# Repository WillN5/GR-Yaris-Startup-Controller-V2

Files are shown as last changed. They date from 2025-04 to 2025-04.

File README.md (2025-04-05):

# GR Yaris Startup Controller V2.0

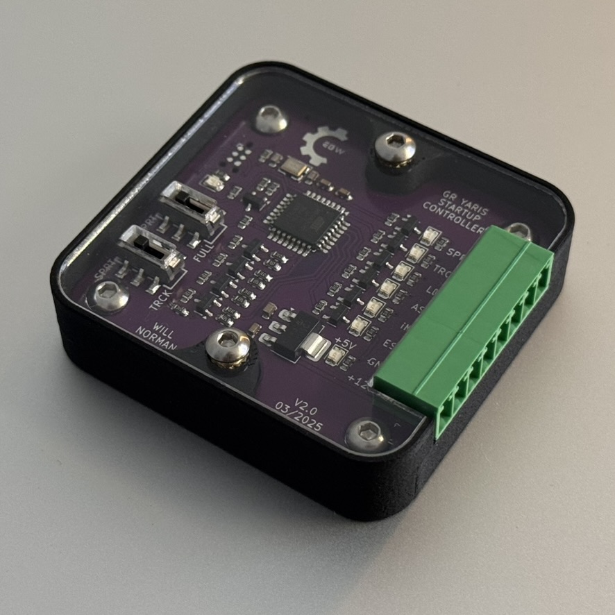
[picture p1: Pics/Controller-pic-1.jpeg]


This device will automatically press any (or all) of the annoying buttons in a GR Yaris when you first start your car:
* Lane Departure Alert (turn off)
* iMT (turn on)
* Auto Stop/Start (turn off)
* Select Sport/Track mode
* Turn ESC to expert mode, or switch ESC fully off

The controller simply presses the buttons (electronically) upon first start up. Original button functionality remains unaffected.

In this repository you will find:
* [Overview & Installation Guide](https://github.com/WillN5/GR-Yaris-Startup-Controller-V2/blob/main/Docs/Overview%20%26%20Install%20Guide.pdf)
* [Car Wiring Information](https://github.com/WillN5/GR-Yaris-Startup-Controller-V2/blob/main/Docs/Car%20Wiring%20Info.pdf)
* [Code](https://github.com/WillN5/GR-Yaris-Startup-Controller-V2/blob/main/Code/Code_Startup_Controller_v2/Code_Startup_Controller_v2.ino)
* [3D Case Files](https://github.com/WillN5/GR-Yaris-Startup-Controller-v2/tree/main/3D%20Files)
* [Pictures](https://github.com/WillN5/GR-Yaris-Startup-Controller-v2/tree/main/Pics)
* [Link to Video Demo](https://youtu.be/CKgJuQoar5g)

Credit for idea goes to MagnusT and his original post here:<br/>
https://www.gr-yaris.co.uk/threads/automatic-shut-off-of-all-lane-assist-everytime-you-start-the-car.2947/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<br/>
This project is a development of that idea to include the additional button presses, wrapped up in a neat package.

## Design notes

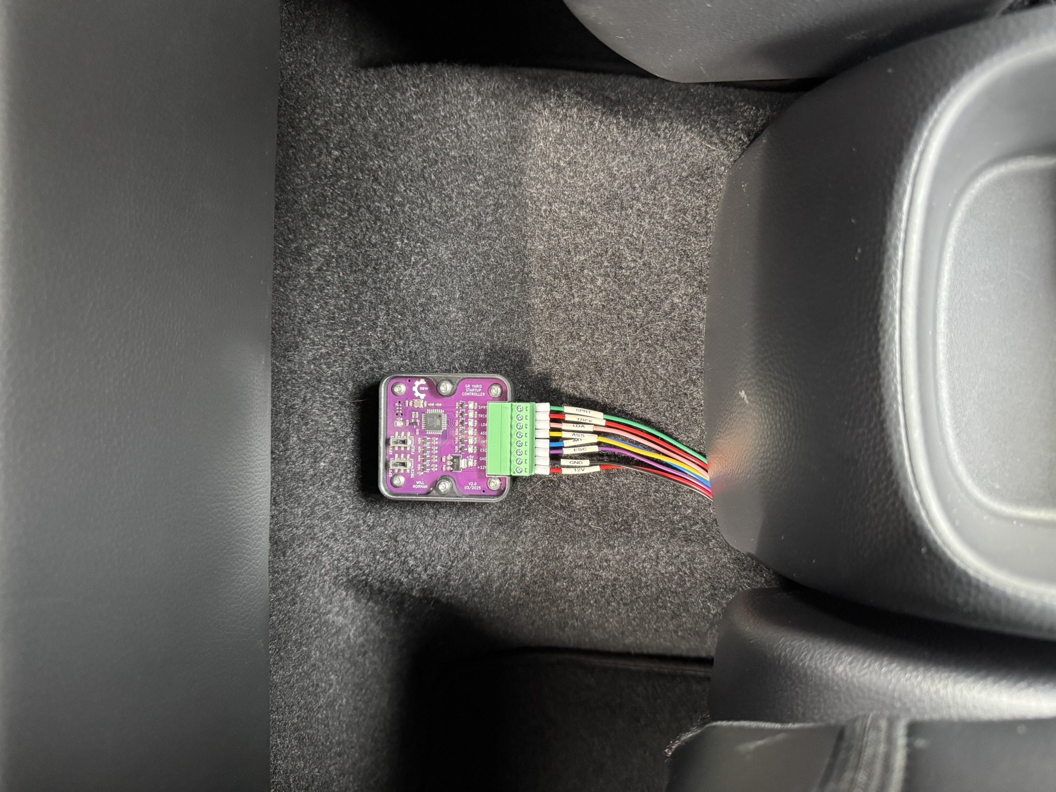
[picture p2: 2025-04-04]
Pics/controller-pic-2.JPEG

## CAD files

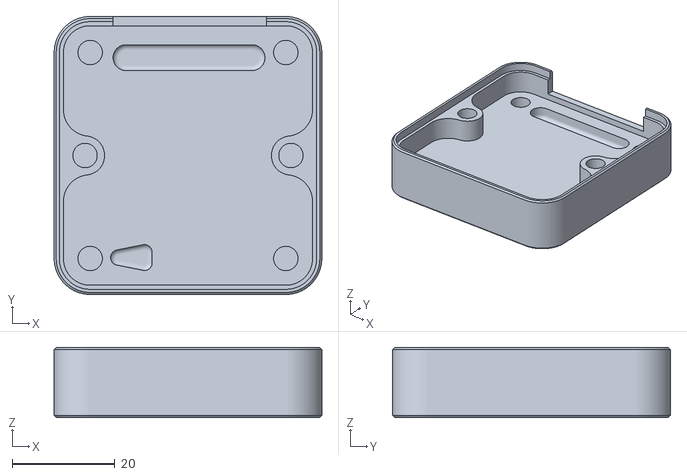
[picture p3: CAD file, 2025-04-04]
3D Files/Case.stl
52.0 x 54.0 x 13.6

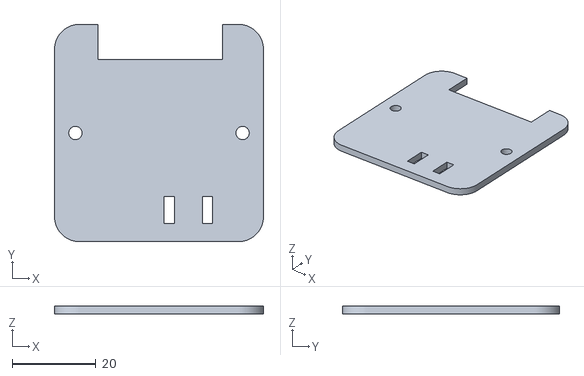
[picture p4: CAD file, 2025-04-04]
3D Files/Cover.stl
50.0 x 52.0 x 2.00

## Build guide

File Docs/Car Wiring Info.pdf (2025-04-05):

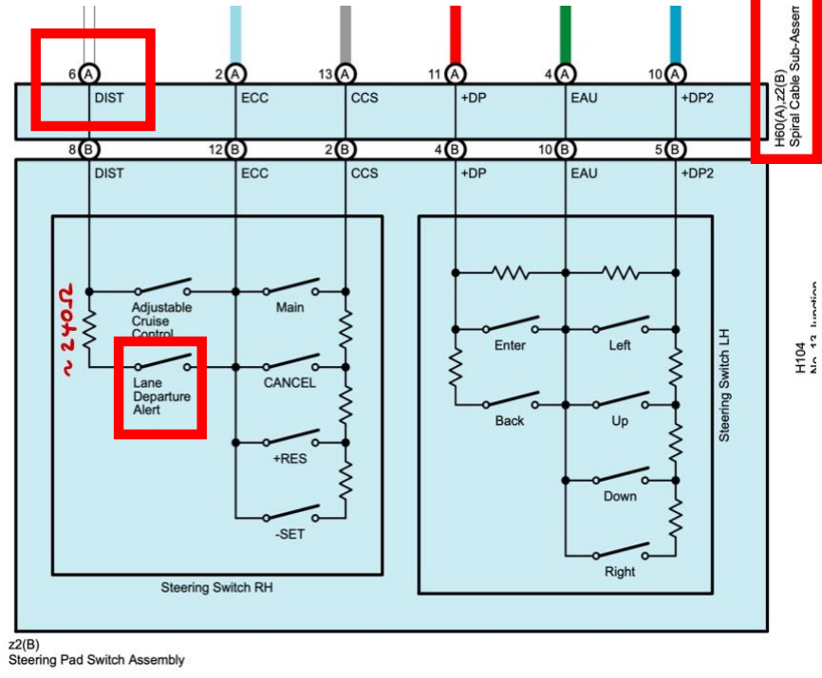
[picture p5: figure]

Control box pin
Socket: | 90980-12369
Plug: | 90980-12370
Plug pin | Colour | Function
1
2
3
4
5
6 | White | Lane departure alert (LDA) | LDA
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
Parts: H60 harness extension (https://www.aliexpress.com/item/1005003780291406.html)
| H60 harness extension (https://www.aliexpress.com/item/1005005530620188.html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)

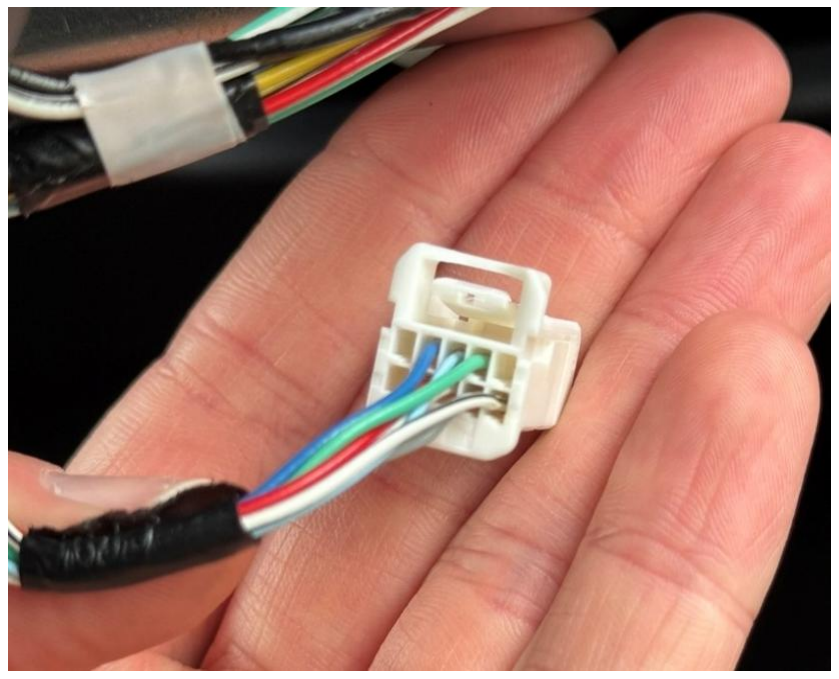
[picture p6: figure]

Socket: | 90980-12367
Plug: | 90980-12368
Plug pin | Colour | Function
1
2
3
4
5
6 | White + Black Stripe | Ground | GND
7
8
9 | Red | Ignition 12V | 12V
10

Parts: H39 harness extension (https://www.aliexpress.com/item/1005004458461883.html)

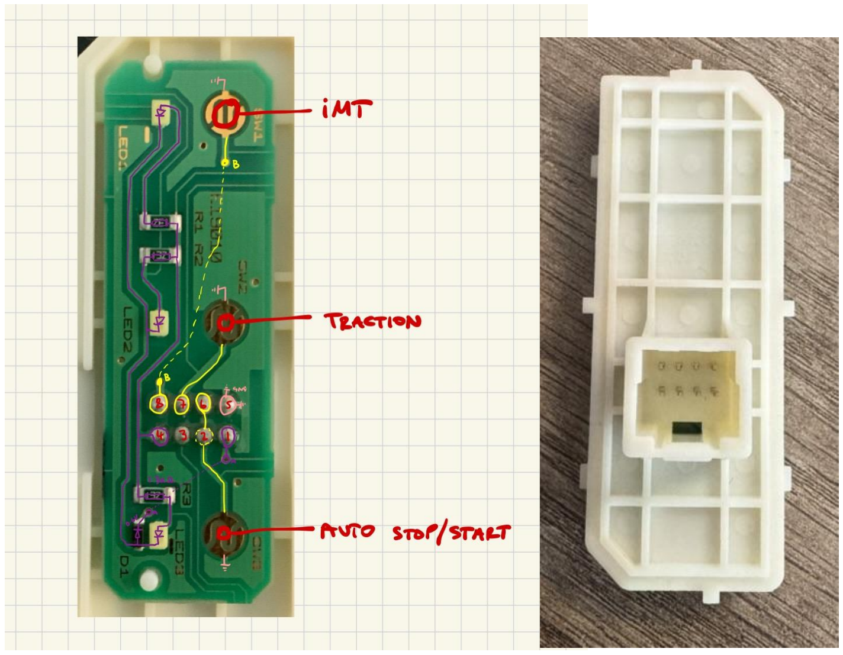
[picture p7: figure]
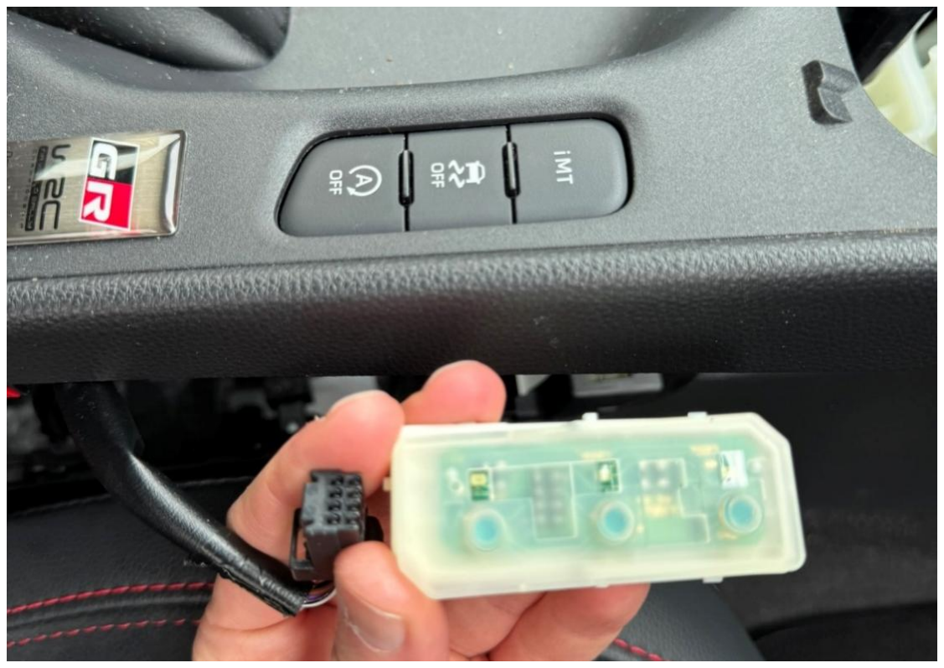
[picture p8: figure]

Crimp pins:
Socket: | 82824-30540 | 4B1160-000 Tokai Rika | 82998-24270
Plug: | 90980-12910 | 4A1330-000 Tokai Rika | 82998-24290
Plug pin | Colour | Function
1 | White + Black Stripe | Ground (LED backlight)
2 | N/C | -
3 | N/C | -
4 | Brown | LED supply?
5 | Brown | Ground (Buttons)
6 | Black | Auto stop/start | A_SS
7 | Purple | Traction/Stability | ESC
8 | Black | iMT | IMT

Parts: Taken a chance with this part (https://www.aliexpress.com/item/1005007362888646.html)
Plug only, no crimps included so not that helpful
Socket: | ?
Plug: | 90980-12558
Plug pin | Colour | Function
1 | N/C | -
2 | White + Black Stripe | Ground (LED backlight)
3 | White + Black Stripe | Ground (Buttons)
4 | Green | Sport mode | M_SP
5 | Blue | Normal mode
6 | Red | Track mode | M_TR
7 | Brown | LED supply?
8 | N/C | -

Parts: Mode select plug + socket + pins, waiting for parts for confirmation of compatibility (https://www.aliexpress.com/item/1005001297466790.html?mp=1)
| Upper slot female version

### 8 pin - Multi Button - iMT / Traction / Stop Start

### 8 pin - Mode Select - Normal / Track / Sport

H60 - 14 pin - Under Steering Wheel - Lane Departure Alert

H39 - 10 pin - Under Steering Sheel - Ignition Power + Ground

1 2 3 4 5 6 7 8

1 2
3 4
5 | 6 | 7 | 8

4 3
2 1
8 | 7 | 6 | 5

1 2 3 4 5 6 7 8

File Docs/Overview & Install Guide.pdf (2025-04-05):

# GR Yaris Startup Controller V2.0

## Overview & Installation Guide

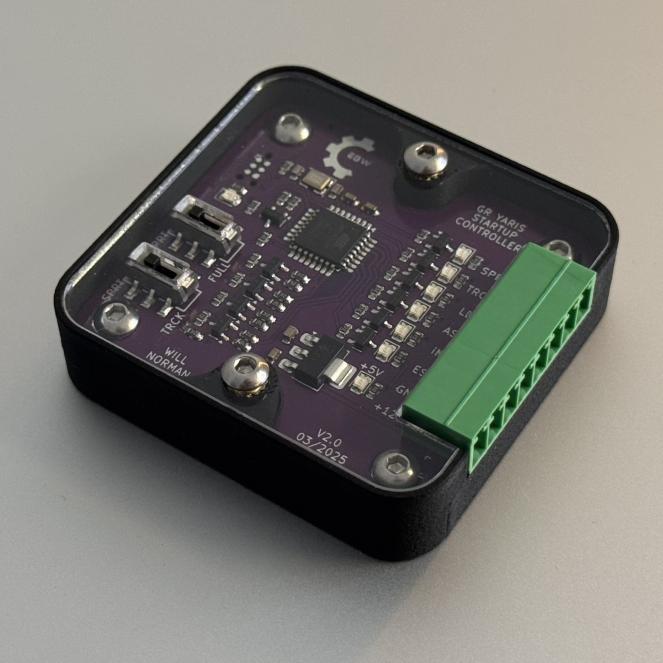
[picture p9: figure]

WILLN on GR-Yaris.co.uk
will.norman@sky.com
GitHub project files (https://github.com/WillN5/GR-Yaris-Startup-Controller-V2/)

I TAKE NO RESPONSIBILITY FOR ANY DAMAGE CAUSED DURING THE INSTALLATION OR OPERATION OF THE DEVICE. INSTALL AT YOUR OWN RISK

05/04/25

# 2. Overview - Operation

Every time the car ignition powers on, the “GR Yaris Startup Controller” turns on and automatically:
- Switches off the lane departure alert
- Switches off auto stop/start
- Switches on iMT
- Selects the driving mode (sport/track)
- Turns ESC to expert mode or fully off

It does this by mimicking button presses electronically (no CAN bus sophistication, just button presses). Original button press functionality remains unaffected.
Link to forum post where idea initially shared by MagnusT (https://www.gr-yaris.co.uk/threads/automatic-shut-off-of-all-lane-assist-everytime-you-start-the-car.2947/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)

If you don’t want all the buttons pressed, wire only the ones you desire and leave the rest unpopulated.

If you don’t feel comfortable splicing into the factory wiring (like me), you can buy short extension harnesses that can be spliced into. See links on subsequent slides for where to purchase these extensions.

# 3. Overview - Design

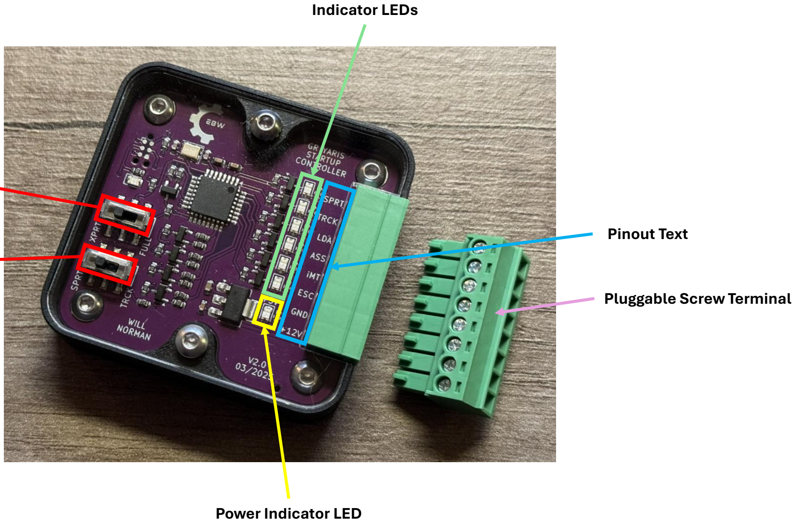
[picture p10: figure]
Pluggable Screw Terminal; Indicator LEDs; Power Indicator LED; Pinout Text

Drive Mode Select Switch
Sport (SPRT)
Track (TRCK)

ESC Select Switch
Expert mode (XPRT) – short button press ESC fully off (FULL) – long button press

# 4. Controller Wiring

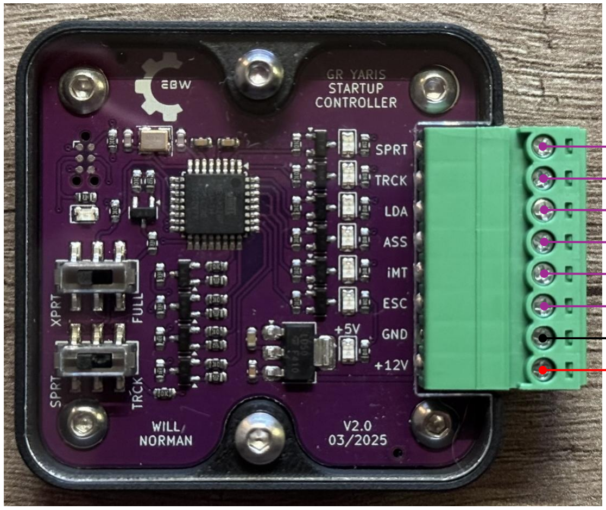
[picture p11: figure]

1. +12V (page 5)
2. GND (page 5)
4. iMT (page 7)
5. ASS - Auto Stop/Start (page 7)
8. SPRT - Sport Mode (page 8)
7. TRCK - Track Mode (page 8)
6. LDA - Lane Departure Alert (page 6)
3. ESC – Stability/Traction Control (page 7)

OEM wiring

Controller wiring tee-d off

# 5. Ignition Power + Ground

The wiring for +12V & GND is found under the steering wheel cowling on the 10-pin plug.
The cowling is removed by undoing 3x screws (rotate the steering wheel to reveal 2 hidden screws)

Pin number 9 (Red) = +12V
Pin number 6 (White & black stripe) = GND

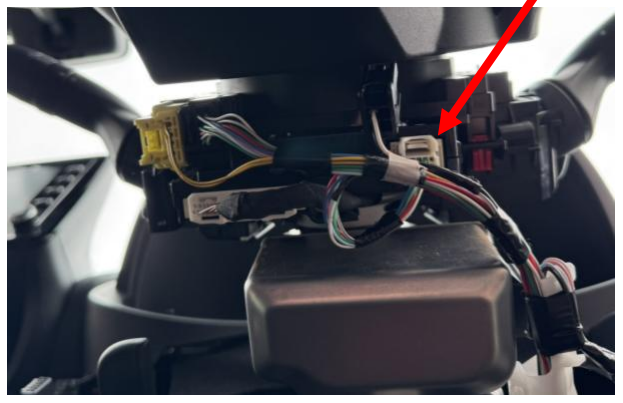
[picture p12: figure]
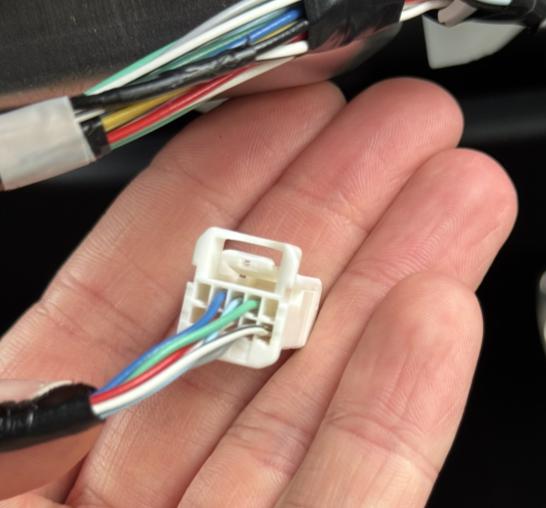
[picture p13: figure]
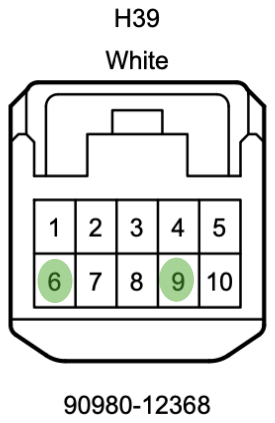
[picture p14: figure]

If you don’t want to splice into the factory wiring, short extension harnesses can be purchased here that you can modify:
10-pin extension harness (https://www.aliexpress.com/item/1005004458461883.html)
Another option that should work (https://www.aliexpress.com/item/1005005530620188.html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)

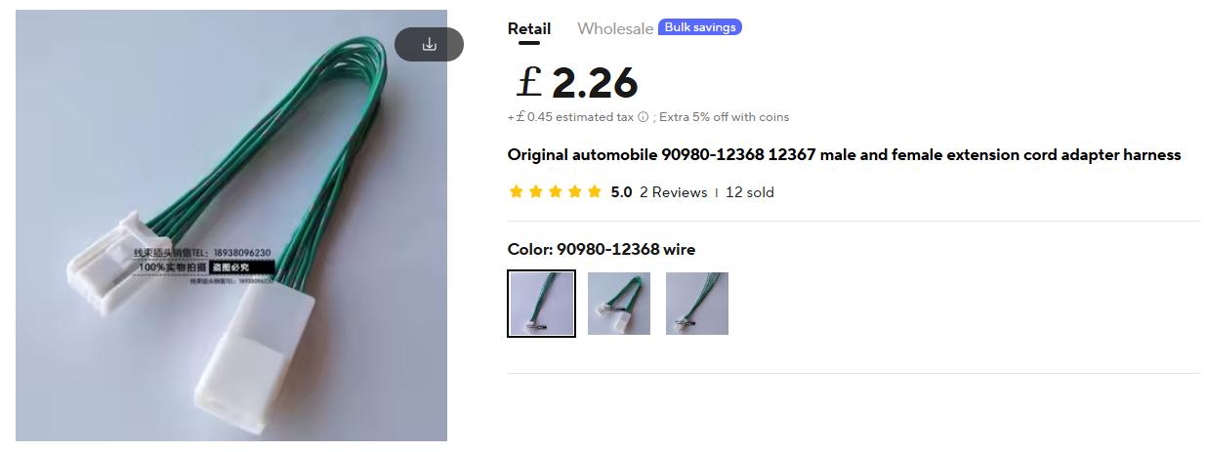
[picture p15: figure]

# 6. Lane Departure Alert

The wiring for LDA is also found under the steering wheel cowling, but on the 14-pin connector

Pin number 6 (White) = Lane Departure Alert (LDA)

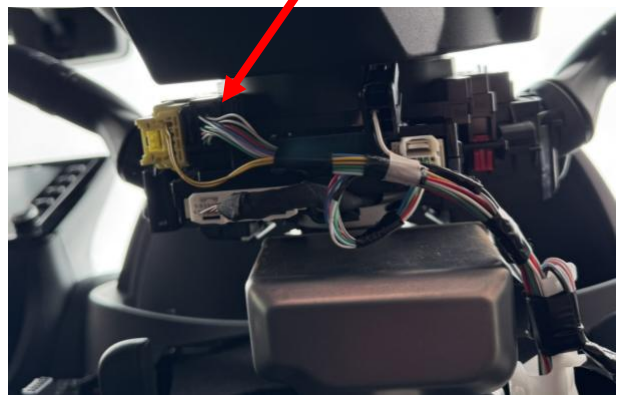
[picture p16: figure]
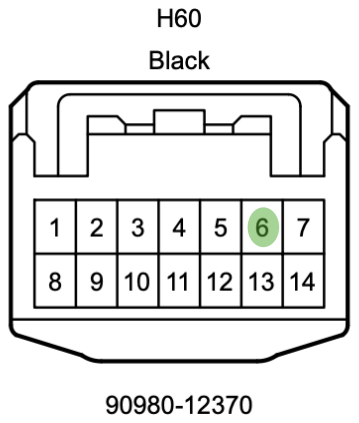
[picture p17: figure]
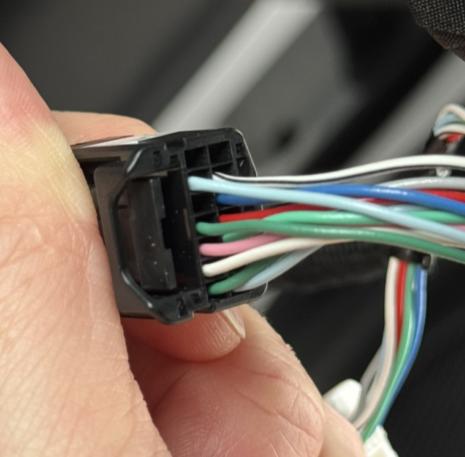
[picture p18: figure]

If you don’t want to splice into the factory wiring, short extension harnesses can be purchased here that you can modify:
14-pin extension harness (https://www.aliexpress.com/item/1005003780291406.html)

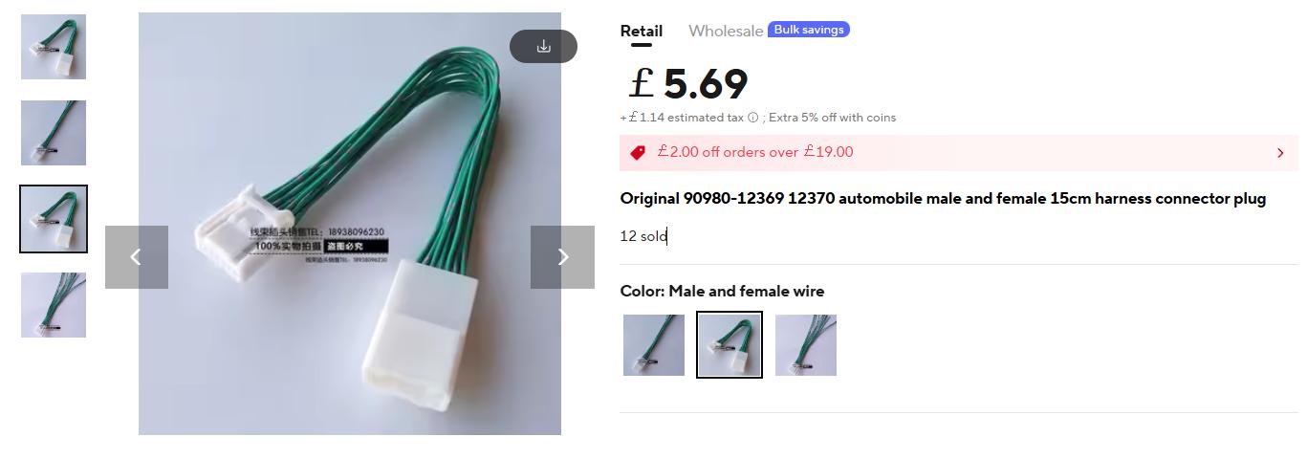
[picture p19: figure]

# 7. iMT, ESC, Auto Stop/Start

The wiring loom needed for iMT, ESC, and Auto Stop/Start is found under the centre console (plugged into the iMT/ESC/Auto stop start button)

Pin number 8 (Black) = iMT
Pin number 7 (Purple) = Stability/Traction Control (ESC)
Pin number 6 (Black) = Auto stop/start (ASS)

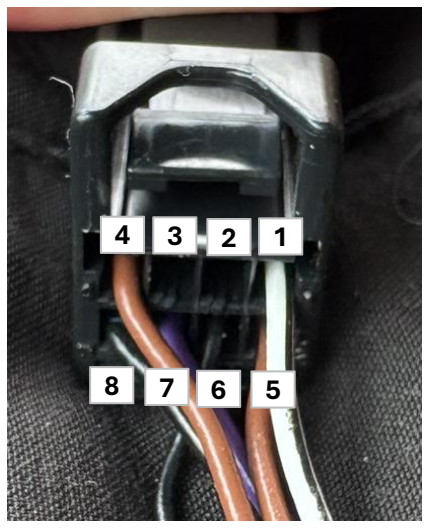
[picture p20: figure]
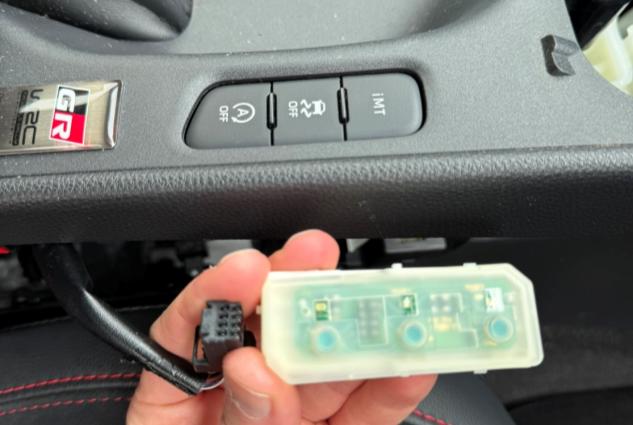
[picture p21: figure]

This 8-pin connector is:

Plug: Tokai Rika 4A1330-000 (Toyota 90980-12910) Socket: Tokai Rika 4B1160-000

# 8. Sport / Track Mode

The wiring loom needed for Sport/Track mode select is found under the centre console (plugged into the drive mode rotary button)

Pin number 4 (Green) = Sport (SPRT)
Pin number 6 (Red) = Track (TRCK)
(Note pins 1 and 8 are unpopulated in the plug but still counted here)

You can wire both sport and track into the controller and use the slide switch on the PCB to choose between them. The slide switch must be in the appropriate position if you decide to wire only Sport or Track.

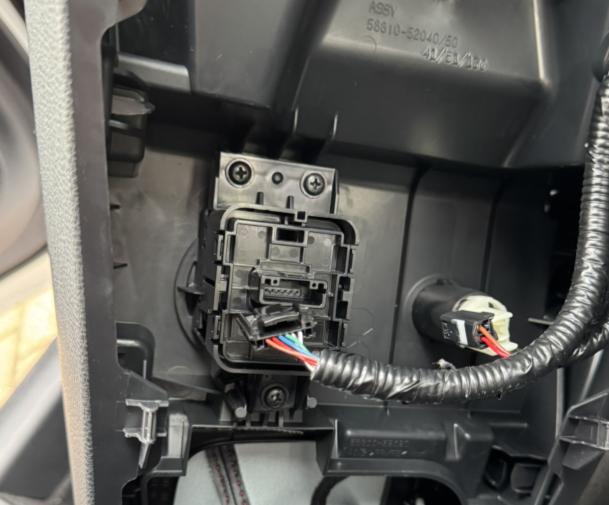
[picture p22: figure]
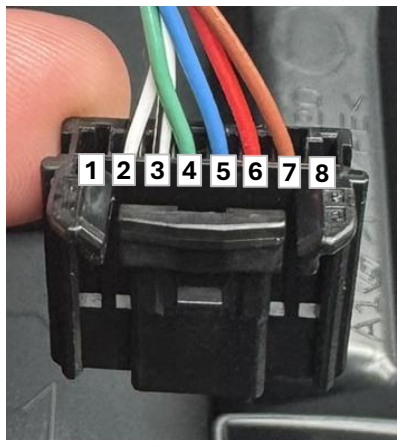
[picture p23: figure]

If you don’t want to splice into the factory wiring, a short extension harness can be made up using these connectors:
8-pin plug + socket + crimp pins (https://www.aliexpress.com/item/1005001297466790.html?mp=1)
(choose the “Upper slot female” version)

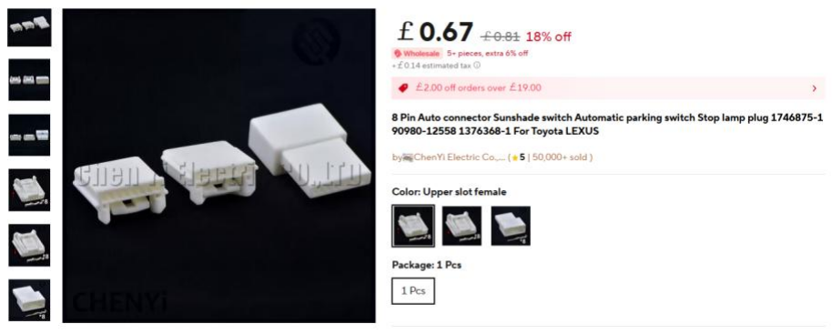
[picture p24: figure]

# 9. Helpful Links

Demo video (https://www.youtube.com/watch?v=CKgJuQoar5g)
Project files and information on GitHub (https://github.com/WillN5/GR-Yaris-Startup-Controller-V2/)
Link to forum post where idea initially discussed by MagnusT (https://www.gr-yaris.co.uk/threads/automatic-shut-off-of-all-lane-assist-everytime-you-start-the-car.2947/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) How to pull apart the centre console (https://www.youtube.com/watch?v=YhoG59Sv5QI)
22 AWG wire (https://www.ebay.co.uk/itm/301224679633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)

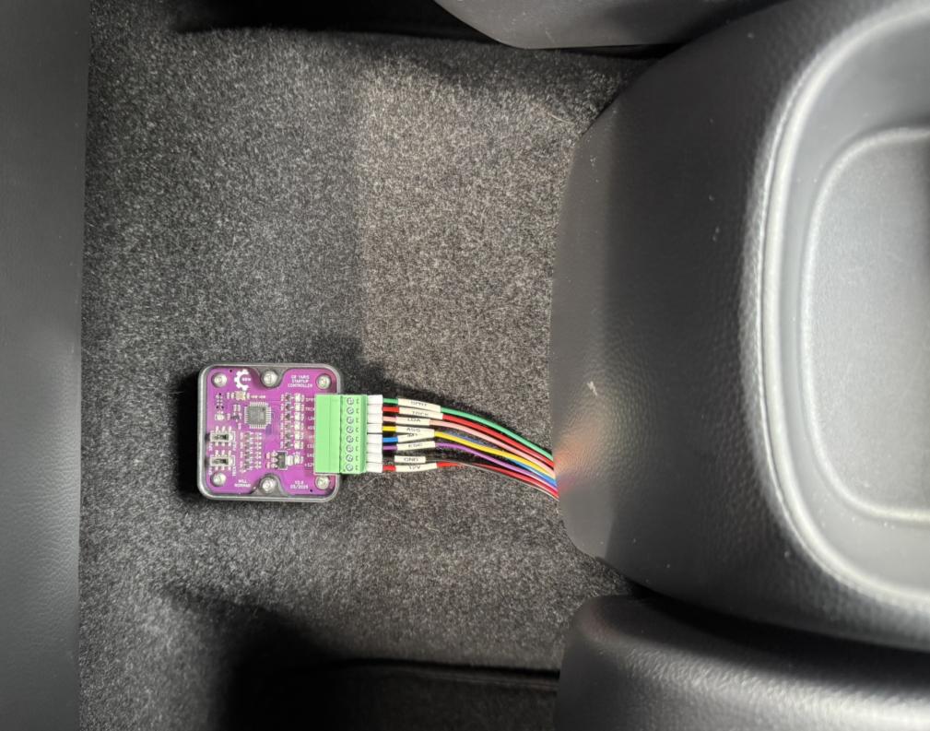
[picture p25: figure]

I’ve chosen to wire mine to the rear of the centre console (for easy access during development)

1) Power & Ground
A. 10-pin extension harness (https://www.aliexpress.com/item/1005004458461883.html)
B. Another 10-pin option that should work (https://www.aliexpress.com/item/1005005530620188.html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)
2) Lane Departure Alert: 14-pin extension harness (https://www.aliexpress.com/item/1005003780291406.html)
3) Sport/Track Mode: 8-pin plug + socket + crimp pins (https://www.aliexpress.com/item/1005001297466790.html?mp=1) (upper slot female version)

# 10. Extension Harnesses

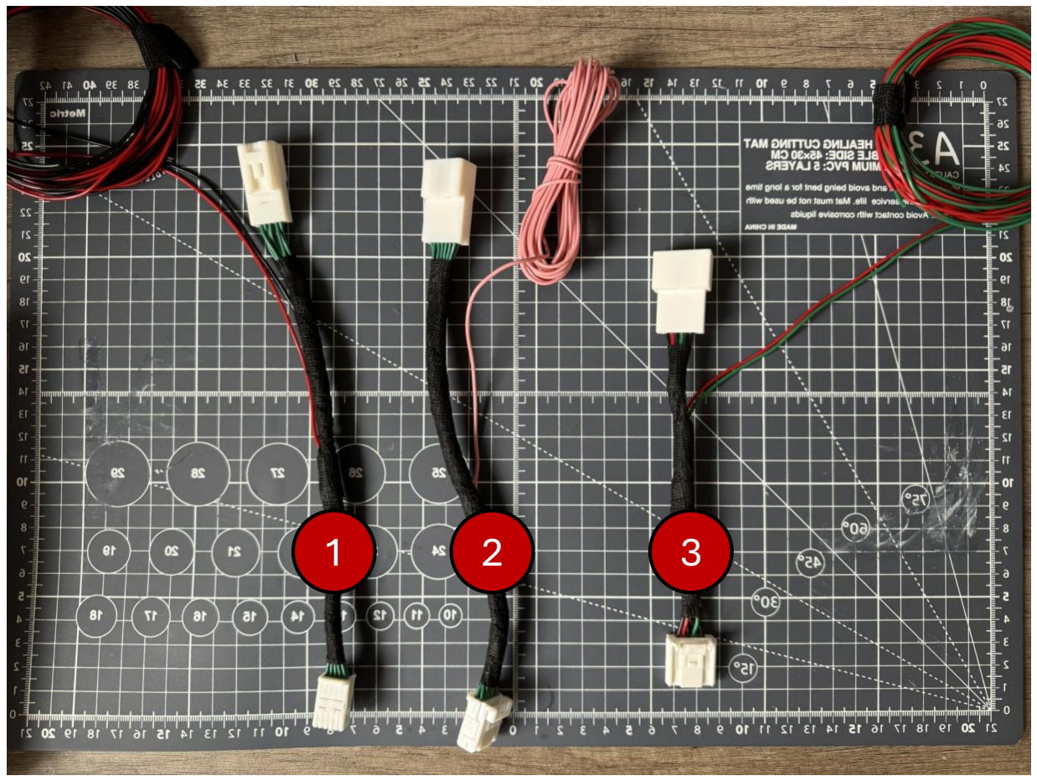
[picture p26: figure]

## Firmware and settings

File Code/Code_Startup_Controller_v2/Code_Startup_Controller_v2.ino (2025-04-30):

// GR Yaris Startup Controller
// Will Norman
// April 2025
// For use with PCB v2.0

// Define all output pins that drive car button presses
#define SWITCH_MODE 10   // sport / track (slide switch determines which chassis signal wire is pulled low)
#define SWITCH_LDA  14   // lane departure alert
#define SWITCH_ASS  15   // auto stop start
#define SWITCH_IMT  16   // iMT
#define SWITCH_ESC  17   // ESC / traction

// Define all output pins of indicator LEDs (flash corresponding LED when button is pressed)
#define LED_SPORT   4   // sport mode led
#define LED_TRACK   3   // track mode led
#define LED_LDA     2   // lane departure led
#define LED_ASS     1   // auto stop/start led
#define LED_IMT     0   // imt led
#define LED_ESC     18  // esc led

// Define input pins (connected to slide switches)
#define INPUT_ESC   5   // Input to determine ESC switch state - expert mode or esc fully off
#define INPUT_MODE  6   // Input to determine track/sport switch state

void setup() {

    // Configure pins as outputs for button 'pressers'
    pinMode(SWITCH_MODE, OUTPUT);
    pinMode(SWITCH_LDA, OUTPUT);
    pinMode(SWITCH_ASS, OUTPUT);
    pinMode(SWITCH_IMT, OUTPUT);
    pinMode(SWITCH_ESC, OUTPUT);
    
    // Configure pins as outputs for indicator LEDs
    pinMode(LED_TRACK, OUTPUT);
    pinMode(LED_SPORT, OUTPUT);
    pinMode(LED_LDA, OUTPUT);
    pinMode(LED_ASS, OUTPUT);
    pinMode(LED_IMT, OUTPUT);
    pinMode(LED_ESC, OUTPUT); 

    // Ensure all output pins are driven low
    digitalWrite(SWITCH_MODE, LOW);
    digitalWrite(SWITCH_LDA, LOW);
    digitalWrite(SWITCH_ASS, LOW);
    digitalWrite(SWITCH_IMT, LOW);
    digitalWrite(SWITCH_ESC, LOW);

    digitalWrite(LED_TRACK, LOW);
    digitalWrite(LED_SPORT, LOW);
    digitalWrite(LED_LDA, LOW);
    digitalWrite(LED_ASS, LOW);
    digitalWrite(LED_IMT, LOW);
    digitalWrite(LED_ESC, LOW);

    // Configure input pins (slide switch inputs)
    pinMode(INPUT_ESC, INPUT);
    pinMode(INPUT_MODE, INPUT);

    // Delay 3s to allow car to startup
    delay(3000);
    
    // Read states of inputs
    bool STATE_ESC = digitalRead(INPUT_ESC);    // HIGH for expert (short press), LOW for ESC fully off (long press)
    bool STATE_MODE = digitalRead(INPUT_MODE);  // HIGH for track, LOW for sport

    // Press buttons sequentially (turn corresponding LED on with button press)

    // LDA on
    digitalWrite(SWITCH_LDA, HIGH);
    digitalWrite(LED_LDA, HIGH);
    delay(3500);
    // LDA off
    digitalWrite(SWITCH_LDA, LOW);
    digitalWrite(LED_LDA, LOW);
    delay(500);

    // iMT on
    digitalWrite(SWITCH_IMT, HIGH);
    digitalWrite(LED_IMT, HIGH);
    delay(500);
    // iMT off
    digitalWrite(SWITCH_IMT, LOW);
    digitalWrite(LED_IMT, LOW);
    delay(500);

    // Auto stop/start on
    digitalWrite(SWITCH_ASS, HIGH);
    digitalWrite(LED_ASS, HIGH);
    delay(500);
    // Auto stop/start off
    digitalWrite(SWITCH_ASS, LOW);
    digitalWrite(LED_ASS, LOW);
    delay(500);


    // Mode select
    // Turn appropriate LED on
    if(STATE_MODE){
        digitalWrite(LED_TRACK, HIGH);
    }else{
        digitalWrite(LED_SPORT, HIGH);
    }
    // Mash mode button 4 times to guarantee button registration
    for(int i=0;i<4;i++){
      digitalWrite(SWITCH_MODE, HIGH);
      delay(500);
      digitalWrite(SWITCH_MODE, LOW);
      delay(500);
    }
    // Switch mode LEDs off
    digitalWrite(LED_TRACK, LOW);
    digitalWrite(LED_SPORT, LOW);
    delay(500);

    // ESC on (must happen after sport/track mode has been selected)
    digitalWrite(SWITCH_ESC, HIGH);
    digitalWrite(LED_ESC, HIGH);
    delay(500);
    // ESC off, check input state to determine if short or long press required
    if(STATE_ESC){
        // If true, short press for expert mode
        digitalWrite(SWITCH_ESC, LOW);
        digitalWrite(LED_ESC, LOW);
    }else{
        // Else long press for ESC fully off (4s total)
        delay(3500);
        digitalWrite(SWITCH_ESC, LOW);
        digitalWrite(LED_ESC, LOW);
    }
}

void loop() {
    // Nothing to do in loop
}
